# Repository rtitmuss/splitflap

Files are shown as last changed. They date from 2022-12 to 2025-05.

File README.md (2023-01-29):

# Split flap

Split flap module driver designed for https://www.printables.com/model/69464-split-flap-display

**WARNING: These files are provided as a reference only, without liability and without any guarantees regarding functionality. This is untested work in progress, really don't assume anything here will work.**

https://user-images.githubusercontent.com/890714/215321878-f9f15342-425b-4259-aaf5-0f672f7ed2bf.mov

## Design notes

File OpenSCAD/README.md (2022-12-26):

# 3d printed Split Flap Generator

This is an OpenSCAD program to generate 3d printed Flaps compatible with [Split Flap Display by David Kingsman](https://www.printables.com/model/69464-split-flap-display).

This generator is useful if you want to:
- Fit more flaps on the build plate, the Prusa Mk3 can print up to 25 flaps at once
- Easily change the letters or ordering of your flaps
- Fixes 'W' to be full height
- Supports flaps with a solid color
- Customise the font or size of the letters

You will need to install the [Expressway Condensed Bold font](https://fontsgeek.com/fonts/Expressway-Condensed-Bold).

## Creating flap STL files

The  `generate_flaps.sh` shows how to create the STL files. You need three STL files for the different layers, the top and bottom layers contain letter halfs, and the middle layer is the flap.

This script outputs several STL files in different directories:
- **letters**: The basic 25 letters Space A-Y.

You also need to pick one of the following. 
- **umlaute**: Z, ÄÖÜ, numbers and symbols; matches the letters on [Split Flap Display](https://www.printables.com/model/69464-split-flap-display).
- **no_umlaute**: Z, numbers and symbols; matches the no umlaute letters on [Split Flap Display](https://www.printables.com/model/69464-split-flap-display).
- **color**: Z, numbers and symbols; replaces $&# with three single color flaps

You may want to generate STL files for single flaps, for example to fix failed prints. You can do this with  `single_flap.sh`, this creates the B/C flap:
```
./single_flap.sh BC
```

## Prusaslicer

The flaps are printed by changing the color mid-print and mid-layer. To enable this in Prusaslicer  make sure that you are in  **Advanced Mode**, or  **Expert mode**  

- In the 'Printer settings>General' tab, and increase the number of extruders to '**2**'
- In the 'Printer settings>Custom Gcode' tab, and open the Tool Change Gcode box... and type in **M600**

Then load the three STL files, for example `flap_AY_0.stl`, `flap_AY_1.stl` and  `flap_AY_2.stl`. In the 'Multi-part object detected' dialog, select **Yes**.

You can then slice and generate the gcode. Optionally edit the gcode file and delete the first M600 instruction, then you don't need to change the filament every time the print starts. Start with the letter color filament (eg white). Part way through the print the printer will stop and bleep, you now need to change to the flap filament (eg black). Follow the instructions on the printer. There will be a wormcast of waste filament - don't pull it off, just hold it and answer that the color is clear. As the printer resumes printing it will expel a little more filament, now is the time to pull it off and discard it. This will happen several times during the print.

## Customization

You can make customizations in `flaps.scad`. For example to change the number of flaps on the build plate, or to try different fonts (hint: the font needs to be narrow to work).

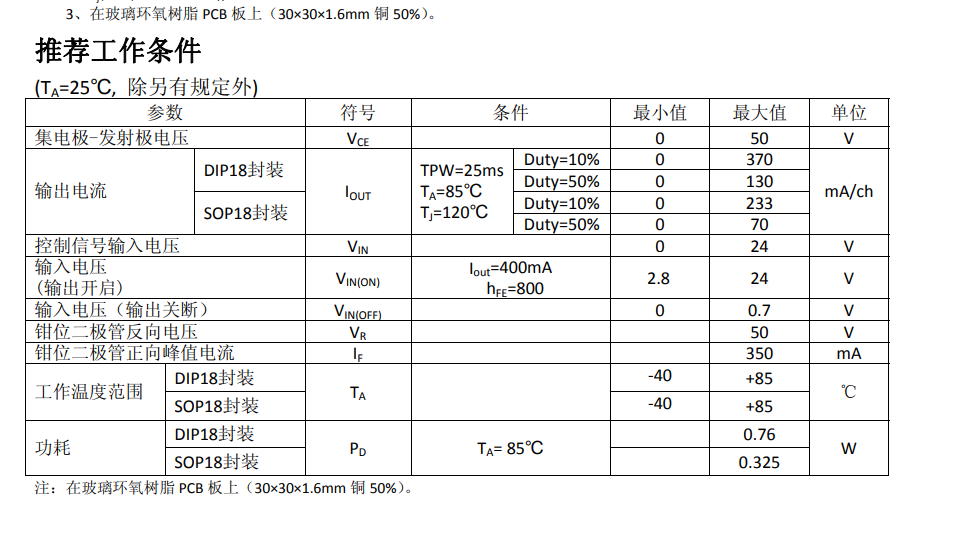
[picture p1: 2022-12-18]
pcb/moduleDriver/images/uln2803a-input-voltage.png

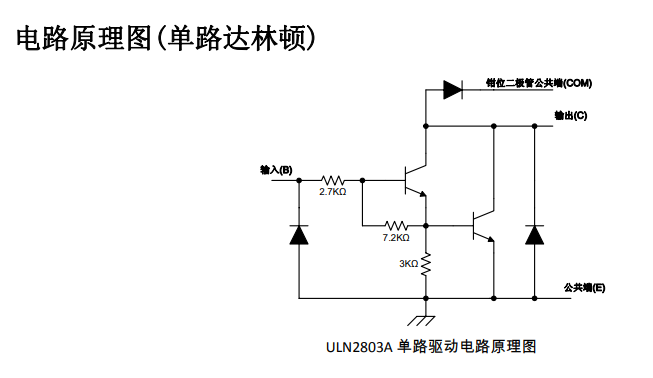
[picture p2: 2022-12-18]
pcb/moduleDriver/images/uln2803a-input-stage.png

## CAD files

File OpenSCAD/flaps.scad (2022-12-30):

// Number of flaps to print in eash set
ROWS = 5;
COLS = 5;

FLAPS = ROWS * COLS;

// Font for the letters
FONT = "Expressway";
FONT_SIZE = 57;
// W needs to be smaller to fit
FONT_SCALE_W = 0.8;

// Thickness of the flap and letters
FLAP_THICKNESS = 1;
LETTER_THICKNESS = 0.4;

// Change this to customise the letters / ordering
// ' ' should be the first and last characters
LETTERS = " ABCDEFGHIJKLMNOPQRSTUVWXYZ0123456789:.-?!$&# ";

// Replace these letters with a solid colored flap
COLOR_FLAP = "";

// Set these variables from generation script
LAYER = 1;              // Layer [0, 1, 2] to render
SET = 0;                // Set to render [0, 1] for 5 rows & cols

SINGLE_FLAP = false;    // Letters for a single flap
COUNT = 4;             // Number of single letters

if (SINGLE_FLAP) {
    // Run FlapLetter for the colored flaps
    FlapLetter(SINGLE_FLAP, LAYER, COUNT);
} else {
    // Run FlapGrid and save the output as an STL file. You need to run this for layers
    // [ 0, 1, 2 ] and to print all the letters needs multiple printJobs.
    FlapGrid(SET, LAYER);
}

// A grid if flaps
module FlapGrid(printJob, layer) {
    offset = printJob * FLAPS;
    letters = substring(LETTERS, offset, min([offset + FLAPS + 1, len(LETTERS)]));
    
    echo(letters)
    
    for (i = [0 : min([FLAPS - 1, len(letters) - 2])]) {
        row = i % ROWS;
        col = floor(i / ROWS);

        if (!(instr(COLOR_FLAP, letters[i]) || instr(COLOR_FLAP, letters[i+1]))) {
            translate([row*45, col*40, 0])
                if (layer == 0) {
                    FlapBottom(letters[i], letters[i+1]);
                } else if (layer == 1) {
                    FlapMiddle(letters[i], letters[i+1]);
                } else {
                    FlapTop(letters[i], letters[i+1]);
                }
        }
    }    
}

// A single flap repeated count times
module FlapLetter(letters, layer, count) {
    for (i = [0 : count - 1]) {
        row = i % ROWS;
        col = floor(i / ROWS);    
            translate([row*45, col*40, 0])
            if (layer == 0) {
                FlapBottom(letters[0], letters[1]);
            } else if (layer == 1) {
                FlapMiddle(letters[0], letters[1]);
            } else {
                FlapTop(letters[0], letters[1]);
            }
        }
}

module FlapMiddle(letter1, letter2) {
    difference() {
        Flap();
        translate([0,0,FLAP_THICKNESS-LETTER_THICKNESS]) {
            Letter(letter1);
        }
        translate([0,0,0]) mirror([0,1,0]) {
            Letter(letter2);
        }
    }
}

module FlapTop(letter1, letter2) {
    intersection() {
        Flap();
        translate([0,0,FLAP_THICKNESS-LETTER_THICKNESS]) {
            Letter(letter1);
        }
    }
}

module FlapBottom(letter1, letter2) {
    intersection() {
        Flap();
        translate([0,0,0]) mirror([0,1,0]) {
            Letter(letter2);
        }
    }
}

module Flap(height=FLAP_THICKNESS) {
    translate([0,0.5,0])
        linear_extrude(height=height, convexity=4)
        polygon([
            [19.5,0],
            [19.5,1.2],
            [21.5,1.2],
            [21.5,2.4],
            [19.5,2.4],
            [19.5,18],
            [21.5,18],
            [21.5,35],

            [-21.5,35],
            [-21.5,18],
            [-19.5,18],
            [-19.5,2.4],
            [-21.5,2.4],
            [-21.5,1.2],
            [-19.5,1.2],
            [-19.5,0],
        ]);
}

module Letter(letter) {
    if (instr(COLOR_FLAP, letter)) {
        Flap(height=LETTER_THICKNESS);
        mirror([0,1,0]) {
            Flap(height=LETTER_THICKNESS);
        }
    } else {
        scale([letter == "W" ? FONT_SCALE_W : 1, 1, 1])
        translate([0, -FONT_SIZE/2, 0])
        linear_extrude(height=LETTER_THICKNESS, convexity=4)
            text(letter, 
                 size=FONT_SIZE, //letter == "W" ? FONT_SIZE_W : FONT_SIZE,
                 font=FONT,
                 halign="center",
                 valign="baseline");
    }
}

function instr(string, letter, i=0) = i < len(string) ?
    string[i] == letter || instr(string, letter, i+1) : false;

function substring(string, start, length) = start < length ?
    str(string[start], substring(string, start + 1, length)) : "";

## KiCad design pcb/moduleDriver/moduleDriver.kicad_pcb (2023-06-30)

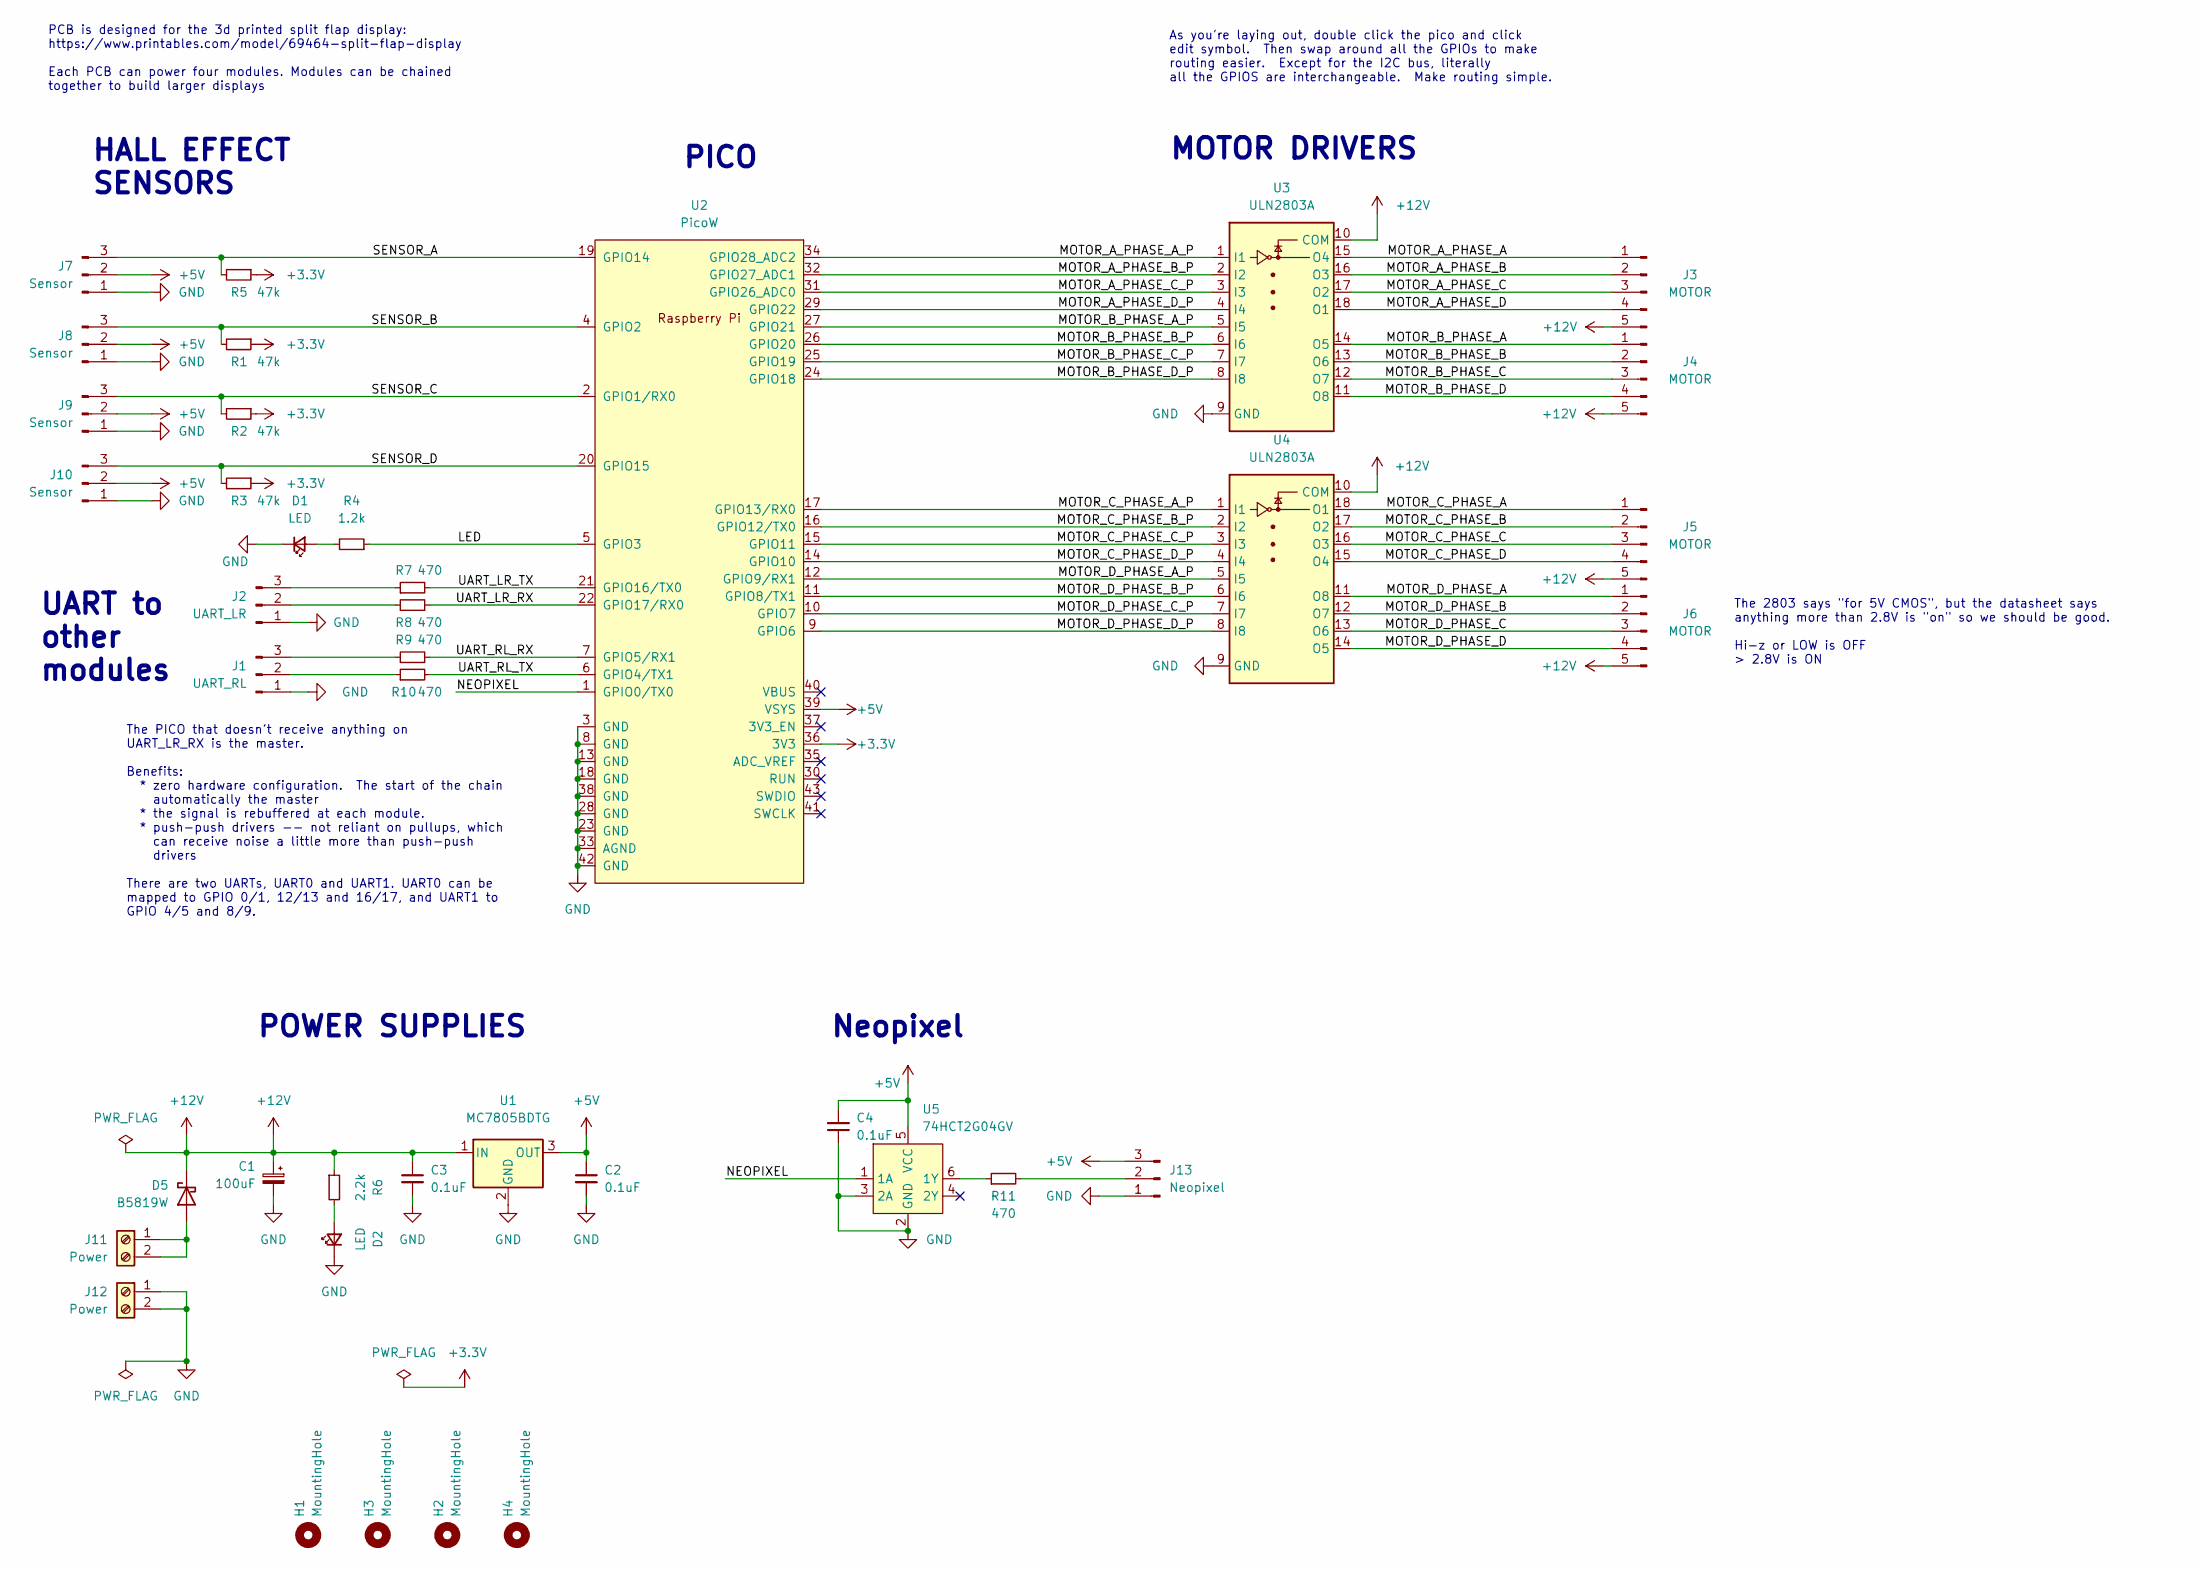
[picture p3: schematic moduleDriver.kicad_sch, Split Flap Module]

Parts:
C1: 100uF; CP_Elec_8x10; LCSC# C176665
C2, C3, C4: 0.1uF; C_0603_1608Metric; LCSC# C14663
D1, D2: LED; LED_0603_1608Metric; LCSC# C72041
D5: B5819W; D_SOD-123; LCSC# C8598
H1, H2, H3, H4: MountingHole; MountingHole_3.2mm_M3_ISO7380
J1: UART_RL; PinHeader_1x03_P2.54mm_Vertical
J2: UART_LR; PinHeader_1x03_P2.54mm_Vertical
J3, J4, J5, J6: MOTOR; JST_XH_B5B-XH-A_1x05_P2.50mm_Vertical
J7, J8, J9, J10: Sensor; PinHeader_1x03_P2.54mm_Vertical
J11, J12: Power; ScrewTerminal-5.08-2P
J13: Neopixel; PinHeader_1x03_P2.54mm_Vertical
R1, R2, R3, R5: 47k; R_0603_1608Metric; LCSC# C25819
R4: 1.2k; R_0603_1608Metric; LCSC# C22765
R6: 2.2k; R_0603_1608Metric; LCSC# C4190
R7, R8, R9, R10, R11: 470; R_0603_1608Metric; LCSC# C23179
U1: MC7805BDTG; TO-252-2; LCSC# C83632
U2: PicoW; RPi_PicoW_SMD_TH
U3, U4: ULN2803A; SOP-18_7x12.5mm_P1.27mm; LCSC# C181731
U5: 74HCT2G04GV; SC-74-6_1.5x2.9mm_P0.95mm; LCSC# C547551

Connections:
+3.3V: R1.1, R2.1, R3.1, R5.1, U2.36 (3V3)
+5V: C2.1, C4.2, J7.2, J8.2, J9.2, J10.2, J13.3, U1.3 (OUT), U2.39 (VSYS), U5.5 (VCC)
+12V: C1.1, C3.1, D5.1 (K), J3.5, J4.5, J5.5, J6.5, R6.1, U1.1 (IN), U3.10 (COM), U4.10 (COM)
/LED: R4.1, U2.5 (GPIO3)
/MOTOR_A_PHASE_A: J3.1, U3.15 (O4)
/MOTOR_A_PHASE_A_P: U2.34 (GPIO28_ADC2), U3.1 (I1)
/MOTOR_A_PHASE_B: J3.2, U3.16 (O3)
/MOTOR_A_PHASE_B_P: U2.32 (GPIO27_ADC1), U3.2 (I2)
/MOTOR_A_PHASE_C: J3.3, U3.17 (O2)
/MOTOR_A_PHASE_C_P: U2.31 (GPIO26_ADC0), U3.3 (I3)
/MOTOR_A_PHASE_D: J3.4, U3.18 (O1)
/MOTOR_A_PHASE_D_P: U2.29 (GPIO22), U3.4 (I4)
/MOTOR_B_PHASE_A: J4.1, U3.14 (O5)
/MOTOR_B_PHASE_A_P: U2.27 (GPIO21), U3.5 (I5)
/MOTOR_B_PHASE_B: J4.2, U3.13 (O6)
/MOTOR_B_PHASE_B_P: U2.26 (GPIO20), U3.6 (I6)
/MOTOR_B_PHASE_C: J4.3, U3.12 (O7)
/MOTOR_B_PHASE_C_P: U2.25 (GPIO19), U3.7 (I7)
/MOTOR_B_PHASE_D: J4.4, U3.11 (O8)
/MOTOR_B_PHASE_D_P: U2.24 (GPIO18), U3.8 (I8)
/MOTOR_C_PHASE_A: J5.1, U4.18 (O1)
/MOTOR_C_PHASE_A_P: U2.17 (GPIO13/RX0), U4.1 (I1)
/MOTOR_C_PHASE_B: J5.2, U4.17 (O2)
/MOTOR_C_PHASE_B_P: U2.16 (GPIO12/TX0), U4.2 (I2)
/MOTOR_C_PHASE_C: J5.3, U4.16 (O3)
/MOTOR_C_PHASE_C_P: U2.15 (GPIO11), U4.3 (I3)
/MOTOR_C_PHASE_D: J5.4, U4.15 (O4)
/MOTOR_C_PHASE_D_P: U2.14 (GPIO10), U4.4 (I4)
/MOTOR_D_PHASE_A: J6.1, U4.11 (O8)
/MOTOR_D_PHASE_A_P: U2.12 (GPIO9/RX1), U4.5 (I5)
/MOTOR_D_PHASE_B: J6.2, U4.12 (O7)
/MOTOR_D_PHASE_B_P: U2.11 (GPIO8/TX1), U4.6 (I6)
/MOTOR_D_PHASE_C: J6.3, U4.13 (O6)
/MOTOR_D_PHASE_C_P: U2.10 (GPIO7), U4.7 (I7)
/MOTOR_D_PHASE_D: J6.4, U4.14 (O5)
/MOTOR_D_PHASE_D_P: U2.9 (GPIO6), U4.8 (I8)
/NEOPIXEL: U2.1 (GPIO0/TX0), U5.1 (1A)
/SENSOR_A: J7.3, R5.2, U2.19 (GPIO14)
/SENSOR_B: J8.3, R1.2, U2.4 (GPIO2)
/SENSOR_C: J9.3, R2.2, U2.2 (GPIO1/RX0)
/SENSOR_D: J10.3, R3.2, U2.20 (GPIO15)
/UART_LR_RX: R8.2, U2.22 (GPIO17/RX0)
/UART_LR_TX: R7.2, U2.21 (GPIO16/TX0)
/UART_RL_RX: R9.2, U2.7 (GPIO5/RX1)
/UART_RL_TX: R10.2, U2.6 (GPIO4/TX1)
GND: C1.2, C2.2, C3.2, C4.1, D1.1 (K), D2.1 (K), J1.1, J2.1, J7.1, J8.1, J9.1, J10.1, J12.1, J12.2, J13.1, U1.2 (GND), U2.3 (GND), U2.8 (GND), U2.13 (GND), U2.18 (GND), U2.23 (GND), U2.28 (GND), U2.33 (AGND), U2.38 (GND), U2.42 (GND), U3.9 (GND), U4.9 (GND), U5.2 (GND), U5.3 (2A)
unnamed: D1.2 (A), R4.2
unnamed: D2.2 (A), R6.2
unnamed: D5.2 (A), J11.1, J11.2
unnamed: J1.2, R10.1
unnamed: J1.3, R9.1
unnamed: J2.2, R8.1
unnamed: J2.3, R7.1
unnamed: J13.2, R11.2
unnamed: R11.1, U5.6 (1Y)

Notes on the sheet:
The 2803 says "for 5V CMOS", but the datasheet says anything more than 2.8V is "on" so we should be good. Hi-z or LOW is OFF > 2.8V is ON
HALL EFFECT SENSORS
UART to other modules
MOTOR DRIVERS
PICO
As you're laying out, double click the pico and click edit symbol. Then swap around all the GPIOs to make routing easier. Except for the I2C bus, literally all the GPIOS are interchangeable. Make routing simple.
Neopixel
PCB is designed for the 3d printed split flap display: https://www.printables.com/model/69464-split-flap-display Each PCB can power four modules. Modules can be chained together to build larger displays
POWER SUPPLIES
The PICO that doesn't receive anything on UART_LR_RX is the master. Benefits: * zero hardware configuration. The start of the chain automatically the master * the signal is rebuffered at each module. * push-push drivers -- not reliant on pullups, which can receive noise a little more than push-push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

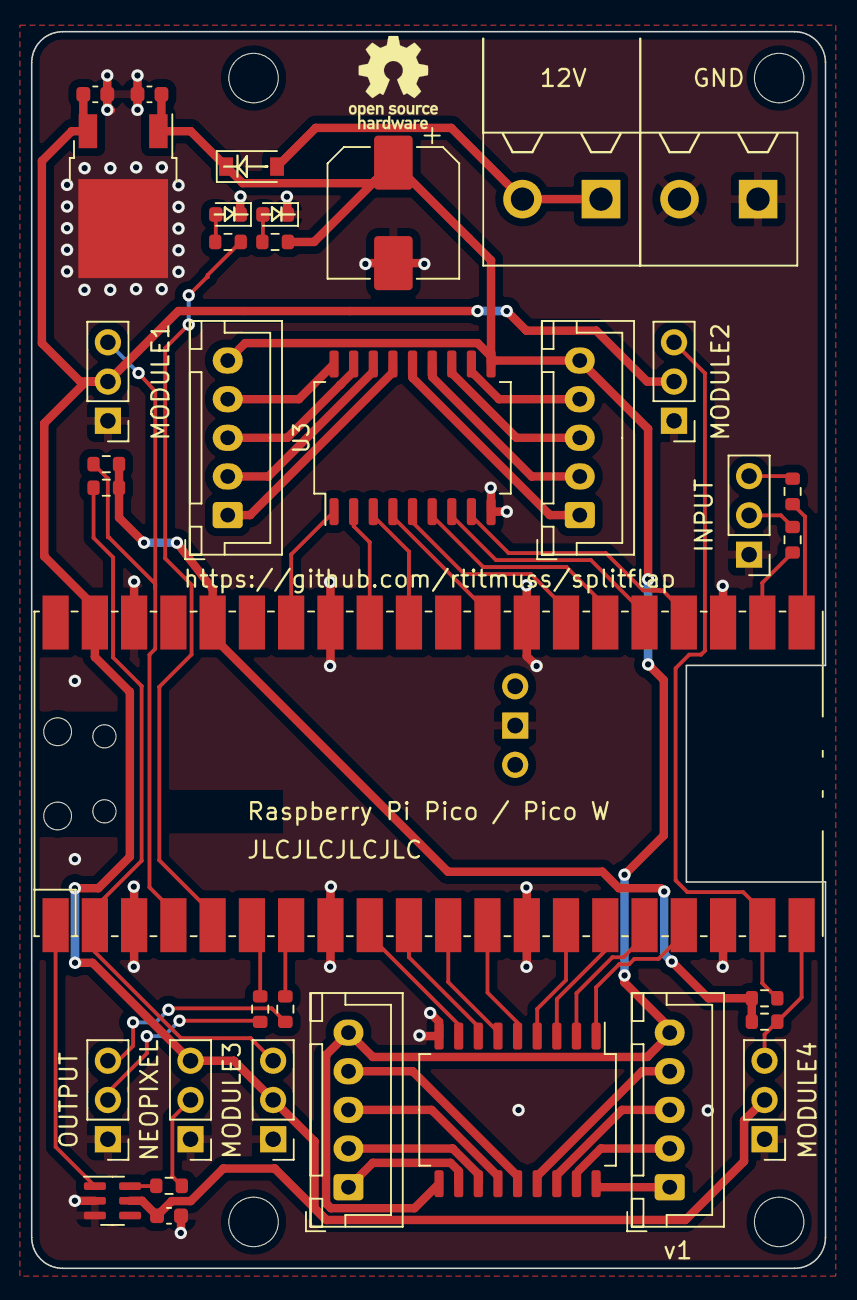
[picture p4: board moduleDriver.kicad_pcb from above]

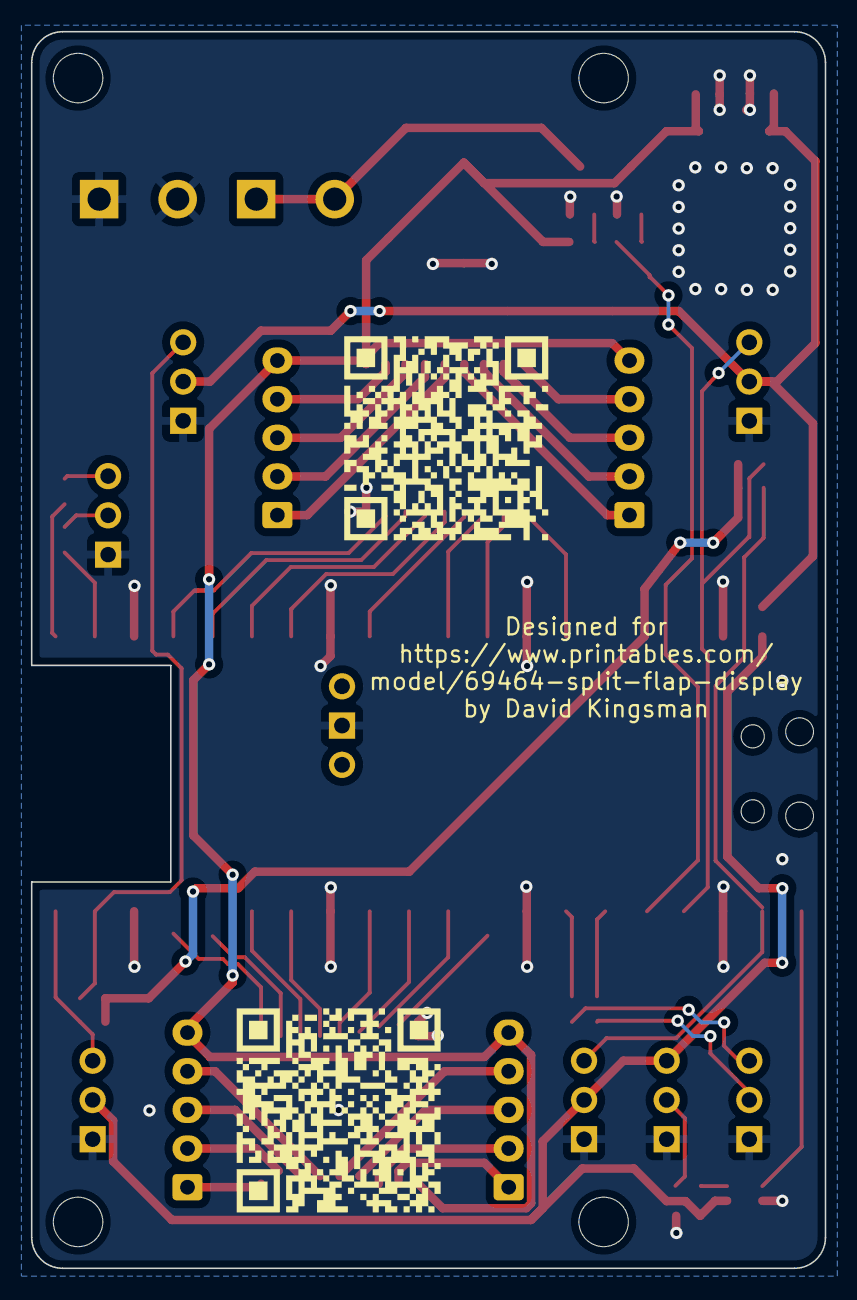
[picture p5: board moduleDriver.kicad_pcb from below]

Board: 2 copper layers, 51.4 x 80.0 mm, 42 parts (2 on the bottom side), 55 nets.

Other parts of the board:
QR*****: github_qrcode
QR*****#2: printables_qrcode

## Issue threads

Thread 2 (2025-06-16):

UART communication between module drivers

TheNoobInventor, 2025-06-16:
First of all, I would like to thank you @rtitmuss and @ccrome for the amazing project, I wanted to work with MicroPython on a split flap display and was very glad to come across your work. I know that there is this disclaimer:

> WARNING: These files are provided as a reference only, without liability and without any guarantees regarding functionality. This is untested work in progress, really don't assume anything here will work.

However, going through the code has helped to improve my Python skills.

I am working on the code to work with 8 flap units, instead of 10, with one module driver driving 2 stepper motors each. Everything works fine, I had to reverse the direction of the motor GPIO pins, before the boolean flag was recently added to the code to have the option of reversing directions. My main issue is getting the two modules to communicate via UART.

I wanted to confirm if there is something I am doing wrong, the main change I have made in the `main.py`file is to use `SourceWords` instead of `SourceHttpd` and having two `ElementGPIO` items instead of 4. I also ensured that I set the `is_picow` flag to `False`. I crossed RX and TX, so RX module 1 to TX module 2 and TX module 1 to RX module 2. Does the UART connection work on your end?

I look forward to your response. Thank you!

rtitmuss, 2025-06-21:
Hey, so fun you are trying this out and it's great you are learning more about Python!

I now have a 24 letter display, with 6 module drivers, working 24x7 so everything is working well for me. I am still planning on making some software improvements this summer with the new crontab function, but I don't have much time to spend on this project at the moment.

It is slightly annoying that the 28BYJ-48 motors can be wired differently, but great you figured out a fix before I added the boolean.

The UART connection does work. As the code is designed to shift letters for each Element it makes sense changing the code to have two `ElementGPIO` if the module is only driving 2 stepper motors. You don't need to cross the wires between the PCBs for the UART, so the wiring between the connectors should be:

```
pin
 1  - 1
 2  - 2
 3  - 3
```

You might want to try input -> output and output -> input depending which module is the primary, running `SourceWords`. Using the latest code if the primary module is on the right when facing the front of the display the silkscreen on the PCB is correct.

Let me know if you get it working, and if not maybe send a picture showing how you've connected the boards.

TheNoobInventor, 2025-06-24:
Thank you for getting back to me, the crontab implementation sounds interesting. My ultimate plan is to get the split flap to work with MQTT, I will probably have to write up a `SourceMQTT` class for that. But unfortunately, at the moment, I haven't been able to get the UART to work. I tried these out:

- Connected **output** to **input**, from **primary** to **downstream**, as you will see in the images I shared below, without crossing the wires.
- Used `SourceHttpd` instead of `SourceWords` for the **primary** module.
- Changed the **primary** panel elements to use two `ElementGpio` instances:
  ```
  panel = Panel([
	ElementGpio(14, 18, 19, 20, 21, reverse_direction=True),
	ElementGpio(15, 9, 8, 7, 6, reverse_direction=True),
	ElementUart(uart_downstream)
	])
  ```
	and the **downstream** panel elements to:
  ```
  panel = Panel([
	ElementGpio(14, 18, 19, 20, 21, reverse_direction=True),
	ElementGpio(15, 9, 8, 7, 6, reverse_direction=True),
	ElementUart(uart_downstream)
	])
  ```
  But even before the setting the panel messages, I should be able to read the upstream UART message which I tried next.
- Connected the **downstream** module to Thonny and ran `main.py` to try to print out the loaded message sent from the **primary** module in this line:
`message = source.load_message(is_stopped, panel.get_motor_position())` but that always returned `None`.

I went deeper in the code to understand the code flow. I changed the `display_offsets` and `display_order` variables in `Config.py` to consider only 4 elements but I ended up with an error that the index was out of range.

It seems like it should be a simple issue to fix but I am not sure what I am doing wrong or forgetting. But please find the connection of the modules below. On a side note, the **primary** and **downstream 1** modules use one motor driver to drive one stepper motor each, they aren't able to drive 2 stepper motors like the other modules can.

Thanks again for your time.

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

rtitmuss, 2025-06-24:
Ah, I think I see the problem with the UART.

Looking from the back my primary is on the left side (so it's easy to plug in the usb, the code is designed that once setup the downstream modules don't need updating), followed by downstream1, downstream2, etc.

Then this PR needs reverting https://github.com/rtitmuss/splitflap/commit/8e4a3443f8256813882d0d1e9839c050dd5419d6 as your "input" and "output" labels on the silkscreen are the wrong way around (sorry!). You can see my board here:

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

You will need to solder a pin header on the "input" of your primary board and connect that to the "output" of your secondary board. Does that help?

--

When you say that the primary and downstream 1 modules can only drive 1 stepper motor, what happens when you connect them both to the single driver chip? Is the behaviour the same on both boards?

--

I should add a warning in the README to be careful with the polarity of the 12v, don't reverse it otherwise you get bad smoke from the driver chip. I learnt the hard way but luckily only destroyed one board.

TheNoobInventor, 2025-06-25:
It works! I had to flip the modules around and connected them like you suggested.

https://github.com/user-attachments/assets/0d52d298-6174-483b-a387-5a0f46f7ce15

I am diagnosing the last two panels. I will also replace the inner drum of the first panel, the fitting between the motor and drum became loose probably due to friction.

To answer you question, I think the chips might be faulty because when I try driving two stepper motors one works fine while the other just hums and doesn't move. I'll have to get some spare chips just in case, I've run of spares.

Thank you so much for your help. The next thing for me is to calibrate the flaps using the `calibrate.py` script then start working on the MQTT implementation.

Closed 2025-06-25.

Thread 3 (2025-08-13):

Replicating flap calibration process

TheNoobInventor, 2025-08-13:
Hello again @rtitmuss, I hope things are going great at your end. I was hoping to get some assistance in replicating the flap calibration procedure.

I've only had time to work on the project recently after receiving some spare motor driver ICs, I have now scaled down to using one module to control `4` panels and the setup works well. I have tried following the steps you outlined for the calibration but without success. So first, I:

- ensured that the panel starts out with the flaps showing the blank flaps, before the letter `'A'`,
- set `num_elements` to `1` (to get it working before eventually moving up to `8`), then
- ran the `calibrate()` function to manually step the flaps. But it does not matter what number I input in the `step()` function, the panel always carries out a full revolution.

I ran the `calibrate()` function as is before I changed the while loop condition to something like `while position != 60:` and incremented the `position` variable to get the panel to stop. This worked but the values I got for the `three_steps` were over `1500`, which is way to high.

I don't know if this is necessary but this is the code I used to call the `calibrate()` function:

```
from machine import Pin, Timer, UART

from Calibrate import calibrate, calculate_offsets
from Panel import Panel
from ElementGpio import ElementGpio
from ElementUart import ElementUart
from UartFrame import UartFrame
from UartMessage import UartMessage

# uart
UART_BAUD_RATE = const(19200)
UART_CHAR_TIMEOUT_MS = const(10)
UART_FRAME_TIMEOUT_MS = const(200)

uart_downstream = UartMessage(
    UartFrame(
        UART(0,
             baudrate=UART_BAUD_RATE,
             tx=Pin(16, Pin.IN, Pin.PULL_UP),
             rx=Pin(17, Pin.OUT, Pin.PULL_UP),
             timeout=UART_CHAR_TIMEOUT_MS)))

panel = Panel([
    ElementGpio(2, 28, 27, 26, 22, reverse_direction=True), # Motor A with sensor B
    #ElementGpio(1, 9, 8, 7, 6, reverse_direction=True), # Motor D with sensor C
    #ElementGpio(14, 18, 19, 20, 21, reverse_direction=True), # Motor B with sensor A
    #ElementGpio(15, 10, 11, 12, 13, reverse_direction=True), # Motor C with sensor D
    #ElementUart(uart_downstream)
])

step = calibrate(panel, num_elements=1)

step()

#calculate_offsets()
```

I do hope it's something trivial I'm missing. Thank you again for your time, I am looking forward to your response!

rtitmuss, 2025-08-25:
hey, sorry for the slow response. did you get it working?

the calibration is for fine tuning the letter positions to avoid off by one errors (eg showing a B instead of A or C). does the display work normally before the calibration, or does it also always do a full rotation?

I need to look at the calibrate code and try it again here to help - I know the instructions are not very clear

TheNoobInventor, 2025-08-26:
Unfortunately I haven't been able to get it to work. I wanted to try again but ran into UART issues connecting to the downstream module. They both work separately so it's most likely a bad cable or connection.

And to answer your question, yes they do a full rotation before calibration, some panels go a bit further. I do get errors connecting to the time and world clock APIs, so that could also be a factor:

```
ntp set time failed
wifi connected 192.168.10.254
[0, 1, 2, 3, 4, 5, 6, 7]
[TIMEZONE] timeapi.io failed: -2
[TIMEZONE] WorldTimeAPI failed: -2
[CRONTAB] New crontab data: {'text': '{CLOCK_STO} '}
word: 'CLOCKSTO' rpm: 15
[CRONTAB] Text: {CLOCK_STO} , Next in: 0ms
loop: 0.00us +/-0.00; interval 0us
mem_free: 136800
panic: missed home
panic: missed home
```

Trying `SourceWords` to print out all As also results in a full rotation:
```
board_source = SourceWords('AAAAAAAA', Display(Config.display_order, Config.display_offsets))
```

I will greatly appreciate any suggestion(s) you might have. I'll make out time to look at the code again later this week. Thanks again.

TheNoobInventor, 2025-08-30:
Thank you for the feedback, this was very very useful. I noticed that three out of the first 4 panels couldn't detect the magnet, so I had to adjust the sensor position until I got the LED to light up when I turn the drum by hand. Now the calibration script works!

Barring any  unforeseen hardware issues, I hope to get all the panels calibrated this weekend. Thanks again for your time and assistance, I'm closing the issue now.

Closed 2025-08-30.

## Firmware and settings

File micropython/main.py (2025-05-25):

import gc
import math
import machine
import micropython
import time

from array import array
from random import randint
from machine import Pin, Timer, UART
from micropython import const

from ElementGpio import ElementGpio
from ElementUart import ElementUart
from InvertedNeoPixel import InvertedNeoPixel
from Panel import Panel
from Source import Source
from SourceUart import SourceUart
from UartFrame import UartFrame
from UartMessage import UartMessage

# primary or downstream panel
is_picow: bool = True
try:
    import network
except ImportError:
    is_picow = False

# leds
rp2040_led = Pin("LED", Pin.OUT)
timer = Timer(period=2000, mode=Timer.PERIODIC, callback=lambda t: rp2040_led.toggle())

panel_led = Pin(3, Pin.OUT, value=0)
neopixel = InvertedNeoPixel(Pin(0), 2)

# uart
UART_BAUD_RATE = const(19200)
UART_CHAR_TIMEOUT_MS = const(10)
UART_FRAME_TIMEOUT_MS = const(200)

uart_upstream = UartMessage(
    UartFrame(
        UART(1,
             baudrate=UART_BAUD_RATE,
             tx=Pin(4, Pin.IN, Pin.PULL_UP),
             rx=Pin(5, Pin.OUT, Pin.PULL_UP),
             timeout=UART_CHAR_TIMEOUT_MS)))

uart_downstream = UartMessage(
    UartFrame(
        UART(0,
             baudrate=UART_BAUD_RATE,
             tx=Pin(16, Pin.IN, Pin.PULL_UP),
             rx=Pin(17, Pin.OUT, Pin.PULL_UP),
             timeout=UART_CHAR_TIMEOUT_MS)))

# panel and element
panel = Panel([
    ElementGpio(2, 28, 27, 26, 22, reverse_direction=False),
    ElementGpio(14, 18, 19, 20, 21, reverse_direction=False),
    ElementGpio(1, 9, 8, 7, 6, reverse_direction=False),
    ElementGpio(15, 10, 11, 12, 13, reverse_direction=False),
    ElementUart(uart_downstream)
])


def downstream_machine_reset():
    seq = uart_downstream.next_seq()
    uart_downstream.send_machine_reset(seq)
    # TODO wait for ack

@micropython.native
def main_loop(source: Source):
    # loop metrics
    loop_buffer_size = 1000
    loop_buffer = array('i', [0] * loop_buffer_size)
    loop_buffer_index = 0

    interval_us = 0

    gc.collect()

    while True:
        t0_us = time.ticks_us()

        is_stopped = panel.is_stopped()
        panel_led.value(not is_stopped)

        message = source.load_message(is_stopped, panel.get_motor_position())
        if message:
            if message == UartMessage.MACHINE_RESET_MESSAGE:
                downstream_machine_reset()
                print("machine reset")
                time.sleep_ms(500)
                machine.reset()

            panel.set_message(message)

            # loop metrics
            loop_average_time = sum(loop_buffer) / loop_buffer_size
            loop_variance = sum((x - loop_average_time) ** 2 for x in loop_buffer) / (loop_buffer_size - 1)
            loop_std_deviation = math.sqrt(loop_variance)
            print("loop: {:.2f}us +/-{:.2f}; interval {}us".format(loop_average_time, loop_std_deviation, interval_us))

            neopixel.fill((randint(0, 255), randint(0, 255), randint(0, 255)))
            neopixel.write()

            gc.collect()
            print('mem_free:', gc.mem_free())

        interval_us = panel.step()

        t1_us = time.ticks_us()
        elapsed_us = time.ticks_diff(t1_us, t0_us)
        delay_us = interval_us - elapsed_us

        if delay_us > 0:
            time.sleep_us(delay_us)

        loop_buffer[loop_buffer_index] = elapsed_us
        loop_buffer_index = (loop_buffer_index + 1) % loop_buffer_size


if is_picow:
    import Config
    from primary.Display import Display
    from primary.SourceHttpd import SourceHttpd
    from provider.Clock import Clock
    from primary.Wifi import Wifi

    wifi = Wifi()
    wifi.connect()

    downstream_machine_reset()
    time.sleep_ms(1000)

    display = Display(Config.display_order, Config.display_offsets)
    clock = Clock.timezone(Config.default_timezone)
    board_source = SourceHttpd(wifi, display, Config.providers, clock, 80)
else:
    board_source = SourceUart(uart_upstream)

main_loop(board_source)

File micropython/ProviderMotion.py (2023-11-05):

import random

import StepperMotor
from Display import Display
from Message import Message
from Provider import Provider
from typing import Union, Tuple


class ProviderMotion(Provider):

    def get_message(self, word: str, display_data: Dict[str, str], display: Display, motor_position: [int]) \
            -> Tuple[Message, Union[int, None]]:
        rpm = int(display_data.get('rpm', 10))
        display_len = display.display_length()

        random_element = random.randint(0, display_len - 1)
        motor_position[random_element] = StepperMotor.stepper_add(
            motor_position[random_element],
            random.randint(int(StepperMotor.STEPS_PER_REVOLUTION / 4), int(StepperMotor.STEPS_PER_REVOLUTION / 2))
        )

        return Message(rpm, [0] * display_len, motor_position), 1

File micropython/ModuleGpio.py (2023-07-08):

from machine import Pin
from Module import Module


class ModuleGpio:

    def __init__(self,
                 hall_sensor,
                 motor_a,
                 motor_b,
                 motor_c,
                 motor_d,
                 offset=None,
                 hall_sensor_active=None):
        self.state = Module(offset=offset,
                            hall_sensor_active=hall_sensor_active)
        self.sensor_pin = Pin(hall_sensor, Pin.IN, Pin.PULL_UP)
        self.motor_pin = list(
            map(lambda x: Pin(x, Pin.OUT, value=0),
                [motor_a, motor_b, motor_c, motor_d]))

    def set_offset(self, offset):
        self.state.set_offset(offset)

    def set_letter(self, letter, rotate_always=None):
        self.state.set_letter(letter, rotate_always)

    def task(self):
        self.state.set_home_pin(self.sensor_pin.value())
        self.state.task()

    def step(self):
        motor_state = self.state.get_motor_pins()
        #print('pins {0:04b}'.format(motor_state))
        self.motor_pin[0].value(motor_state & (1 << 0))
        self.motor_pin[1].value(motor_state & (1 << 1))
        self.motor_pin[2].value(motor_state & (1 << 2))
        self.motor_pin[3].value(motor_state & (1 << 3))

    def steps_to_rotate(self):
        return self.state.steps_to_rotate()

    def is_panic(self):
        return self.state.is_panic()

    def is_stopped(self):
        return self.state.is_stopped()

    def get_status(self):
        if self.state.is_panic():
            return 'p'
        if self.state.is_stopped():
            return '_'
        return '|'

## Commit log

2022-12-11 Initial PCB
    [moduleDriver.kicad_pcb, moduleDriver.kicad_sch, pico.kicad_sch]
2022-12-11 Simple PCB fixes
    - Change C2, C3, C5, C6 all to 1uF
    - Delete R4
    [moduleDriver.kicad_pcb, moduleDriver.kicad_sch]
2022-12-11 Added 12v led
    [moduleDriver.kicad_pcb, moduleDriver.kicad_sch]
2022-12-11 Added level translation IC and pull up on PWR_ENABLE_IN_3V3
    [moduleDriver.kicad_sch]
2022-12-11 Add voltage divider for SENSOR_OUT
    [moduleDriver.kicad_sch]
2022-12-11 Inital layout for voltage level translation
    [moduleDriver.kicad_pcb, moduleDriver.kicad_sch]
2022-12-11 Rework pico layout
    [moduleDriver.kicad_pcb, moduleDriver.kicad_sch]
2022-12-12 Reduce traces on ground plane
    [moduleDriver.kicad_pcb]
2022-12-12 Add LCSC part numbers
    [moduleDriver.kicad_sch]
2022-12-13 Pick jlcpcb basic parts
    [moduleDriver.kicad_sch]
2022-12-13 Fix gap between power connectors
    [moduleDriver.kicad_pcb]
2022-12-13 Top silkscreen
    [moduleDriver.kicad_pcb]
2022-12-14 Back silkscreen
    [moduleDriver.kicad_pcb]
2022-12-14 Update schematic after review
    [moduleDriver.kicad_pcb, moduleDriver.kicad_sch]
2022-12-14 Update footprints on PCB
    [moduleDriver.kicad_pcb, moduleDriver.kicad_sch]
2022-12-15 Fix pull up/downs on buffer
    [moduleDriver.kicad_pcb, moduleDriver.kicad_sch]
2022-12-15 Readability improvements
    [moduleDriver.kicad_sch]
2022-12-15 Updated layout
    [moduleDriver.kicad_pcb, moduleDriver.kicad_sch]
2022-12-16 Iterate on level translation
    [moduleDriver.kicad_pcb, moduleDriver.kicad_sch]
2022-12-18 more modular maybe?
    [moduleDriver.kicad_sch]
2022-12-18 oh, this is much more simpler
    [moduleDriver.kicad_sch]
2022-12-18 cleaned up schematic
    [moduleDriver.kicad_sch]
2022-12-18 added a couple comments
    [moduleDriver.kicad_sch]
2022-12-18 update more text
    [moduleDriver.kicad_sch]
2022-12-18 erm... added dip switches for module addressing.... and some notes. but now there's a better way...
    [moduleDriver.kicad_sch]
2022-12-18 yep, this is the winner
    [moduleDriver.kicad_sch]
2022-12-18 checking voltage levels. Everythign looks correct
    [moduleDriver.kicad_sch]
2022-12-18 Remove unneeded files
    [pico.kicad_sch]
2022-12-18 Restarting layout
    [moduleDriver.kicad_sch]
2022-12-18 Initial layout for new schematic
    [moduleDriver.kicad_pcb, moduleDriver.kicad_sch]
2022-12-18 Add mounting holes and fix silkscreen
    [moduleDriver.kicad_pcb, moduleDriver.kicad_sch]
2022-12-18 Add serial resistors to uart
    [moduleDriver.kicad_pcb, moduleDriver.kicad_sch]
2022-12-18 Visual tweaks
    [moduleDriver.kicad_pcb]
2022-12-18 Fix regulator caps
    [moduleDriver.kicad_sch]
2022-12-18 Add missing gnd vias
    [moduleDriver.kicad_pcb]
2022-12-18 Silk screen fixes
    [moduleDriver.kicad_pcb]
2022-12-19 Move caps, add JLCJLCJLCJLC to silk screen
    [moduleDriver.kicad_pcb]
2022-12-19 Add support for neopixel
    [moduleDriver.kicad_pcb, moduleDriver.kicad_sch]
2022-12-19 Add more vias for thermal release
    [moduleDriver.kicad_pcb]
2022-12-19 Add diode symbol to silk screen
    [moduleDriver.kicad_pcb]
2022-12-19 Tweak ground fill
    [moduleDriver.kicad_pcb]
2022-12-19 Improve screw clearance
    [moduleDriver.kicad_pcb]
2022-12-26 Add OpenScad files to generate flaps
    [flaps.scad]
2022-12-30 Fix off by one error generating letters
    [flaps.scad]
2023-01-29 Initial support for UART between clusters
2023-01-30 Add UART timeout and report module status
2023-02-01 Swap uarts (pcb silk is wrong)
    [main.py]
2023-02-04 Add uart protocol with crc and seq numbers
2023-02-04 Add max_steps to uart protocol to synchronize when the flaps stop
2023-06-30 Fix uart silkscreen
    [moduleDriver.kicad_pcb]
2023-07-02 Reduce stepper speed
    The new stepper motors stall at higher speeds
    [Cluster.py]
2023-07-02 Add UART constants
2023-07-02 Add zero position offset
    This allows for variations due to the hall sensor pcb
2023-07-02 Fix step count when forced rotation to same letter
    [Module.py]
2023-07-07 Use named parameters to construct Frame
    Micropython does not support defaults for namedtuples so this needs
    a helper function
2023-07-07 Add variable stepper rpm
2023-10-08 Restructured Code for Enhanced Modularity and Clarity
    This commit restructures the codebase to improve modularity and
    readability.
    Previously, the code sent letters from the primary to downstream
    modules over UART. To simplify the downstream modules, the approach
    now involves sending only delay and motor position data. This change
    centralizes the mapping of letters to motion, including calibration
    offsets, within the primary module.
    The Panel class has been updated to encapsulate one or more Elements,
    which can represent physical letters or, in a future PR, virtual sets
    of letters representing downstream modules.
    The main loop has been redesigned to avoid blocking while the motors
    move to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
    [Element.py, ElementGpio.py, Message.py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]
2023-10-13 Add simple uart protocol
2023-10-14 Simulate behaviour of downstream Elements
    Allowing prediction of the number of steps and motor positions
2023-10-14 Fix UartFrame test
2023-10-15 Fix sweep and add random pattern
    [Message.py, SourceWords.py]
2023-10-28 Add StepperMotor test
2023-10-29 Fix word_end_in_sync so Elements always rotate
    [Message.py]
2023-11-01 Add __str__ for debugging in repl
    Use ctrl-c and print(panel) to see state
2023-11-02 Refactor uart seq to UartMessage
2023-11-02 Add machine reset over uart
    [UartMessage.py, main.py, test_UartMessage.py]
2023-11-03 Add a I'm feeling luck button
2023-11-05 Fix wifi to work with power on reset
    [SourceHttpd.py, main.py]
2023-11-12 Fix imports on secondary units
    There were errors loading modules with http dependancies
    [main.py]
2023-11-15 Use network order in pack/unpack
    Fixes crash with invalid data
    [UartMessage.py, test_UartMessage.py]
2025-05-18 Allow the motor direction to be reversed
    The direction of 28BYJ-48 are not consitent, and my newer motors
    run in the opposite direction
    [ElementGpio.py, main.py]
2025-05-18 Swap UART
    This now matches the labelling on the silk screen and means the wires
    are shorter
    [main.py]
2025-05-25 Default to displaying messages from crontab file
    Allow overrides to be sent over http, after a short timeout
    return to using crontab as a message source
    [SourceHttpd.py]
2025-05-25 Use correct timezone for crontab file
    [Config.py, SourceHttpd.py, main.py]
2025-05-25 Fix http server to work with longer post bodies
    [SourceHttpd.py]
2025-05-25 Refactor Clock timezone API
    Replace Clock.now(timezone) with Clock.timezone(timezone).now().
    This change makes the timezone handling more explicit and type-safe by
    returning a timezone-aware clock class instead of passing timezone as a
    parameter to now().
    [Clock.py, main.py]
2025-06-07 Calibrate new letters
    And slightly improve the calibration code and add instructions
2025-07-08 Always used cached timezone files
    The cached version was being discarded on error which meant the
    splitflap display showed UTC instead of local time
    [Clock.py]
2026-06-24 Fix website presets to use correct provider parameters
    The presets were never updated after the provider interface was
    refactored to use a JSON args dict. They were still packing
    parameters into the text field using {provider}|param syntax,
    which was displayed literally on the flaps.
    Presets now send proper form fields (format, text, timezone, lang)
    matching the crontab JSON format. Also accept POST /display
    requests with a format field but no text field, since some
    providers (Art, Motion, etc) don't need text.
    [SourceHttpd.py]
2026-06-24 Fix stale test cases for Httpd and SourceHttpd
    test_Httpd.py:
    - Update handler lambdas to match current (url, body) signature
    - Update process_http_request calls to use (method, url, body)
    - Compare against bytes not strings
    - Server error test expects ValueError (error handling is in poll())
    - Rename test class from SourceHttpdTest to HttpdTest
    test_SourceHttpd.py:
    - Add missing imports (Union, Tuple, Dict, List, Display)
    - Fix MockProvider.get_message to match current args signature
    - Fix MockDisplay to include all required attributes
    - Use 'MESSAGE' provider key instead of '{MESSAGE}'
    - Fix process_post_display to pass body bytes, not full request
    - Replace references to removed display_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
2026-06-24 Add retry logic for dad joke HTTPS requests
    The Pico W MbedTLS stack intermittently fails with
    MBEDTLS_ERR_SSL_CONN_EOF. Retry up to 3 times with a 2 second
    delay between attempts before giving up.
2026-06-24 Add status display area and dark mode to web UI
    - Add GET /status endpoint returning JSON with source, data, rows, cols, mem_free, uptime, wifi
    - Track start_ticks for uptime calculation
    - Dark theme with #1a1a1a background and #f0c040 yellow accents
    - Flap visualization grid showing current display state
    - Status bar with wifi indicator, source, uptime, and free memory
    - Auto-polls /status every 5 seconds
2026-06-28 Fix flap visualization colors and status text
    - Flaps and title use white on dark gray, matching real split-flap look
    - Status endpoint returns actual displayed text after provider processing
    - Store last_word on Provider after get_message runs
    - Title background matches page background
    [Provider.py, SourceHttpd.py]
2026-06-28 Add weather forecast to clock provider
    - Fetch current temperature and 3-hour weather outlook from Open-Meteo API
    - Add format codes: %t (current temp), %w (weather condition)
    - Weather codes: SUNNY, CLOUDY, FOG, DRZZLE, RAIN, FZRAIN, SNOW, SHOWER, SLEET, STORM
    - 6-char padded weather codes with 3-char right-aligned temperature
    - gc.collect() + 3-retry pattern for HTTPS on Pico W
    - 10-minute weather cache to reduce API calls
    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
2026-06-28 Initialize last_word as class attribute to avoid AttributeError
    [Provider.py]
2026-06-28 Stream static files directly to socket, gc.collect after serving, pass sock to all handlers
